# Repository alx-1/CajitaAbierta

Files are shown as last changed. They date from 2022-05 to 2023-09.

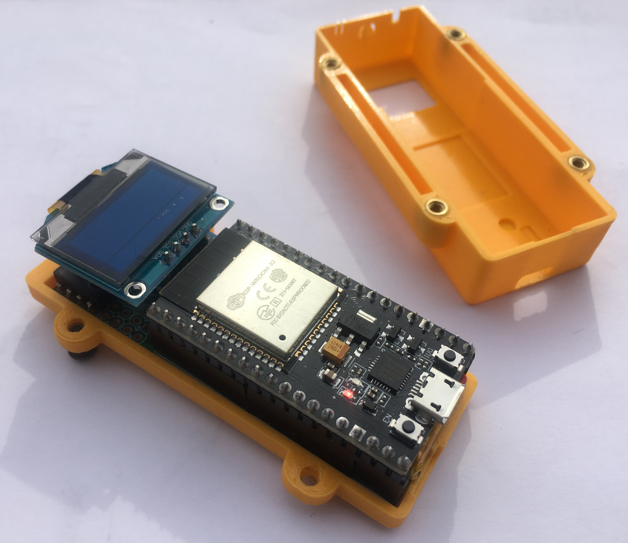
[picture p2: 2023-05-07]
media/images/cajita_abierta_01.JPG

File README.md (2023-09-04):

# CajitaAbierta

The repo for the firmware is now at : https://gitlab.com/darknessdesigner/cajitaabierta

Start with the howtos : https://github.com/alx-1/CajitaAbierta/wiki

Breakout wireless sensor circuit + software for the nodemcu ESP32S board.

Can send sensor data to :

touchOSCBridge

chataigne

hydra over node

and the TDLF module : https://github.com/alx-1/technologies-de-la-fete

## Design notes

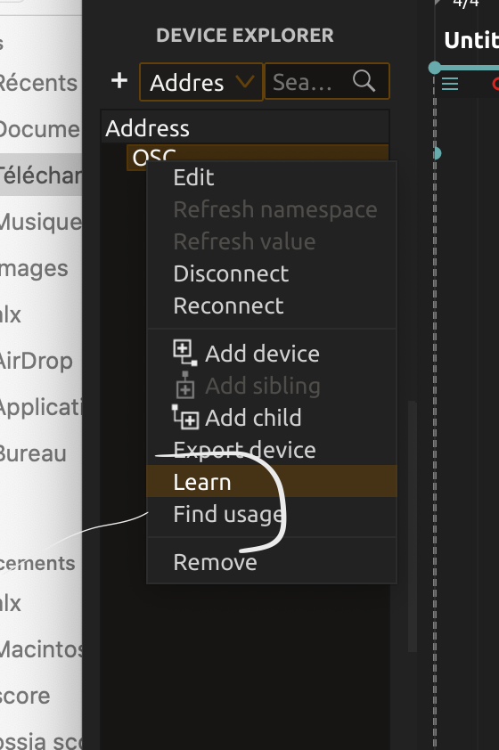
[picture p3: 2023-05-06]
media/images/ossia_osc_learn.png

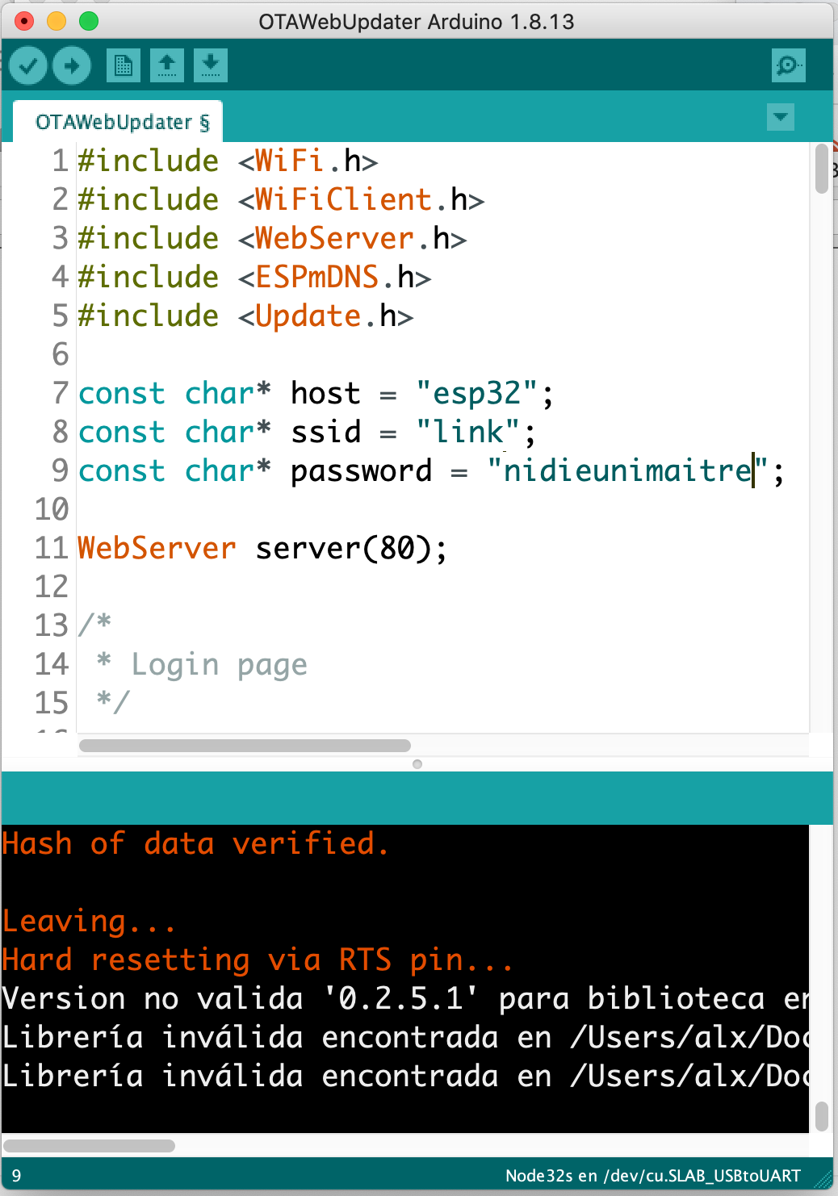
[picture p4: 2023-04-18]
media/images/OTAWebUpdater_change_credentials.png

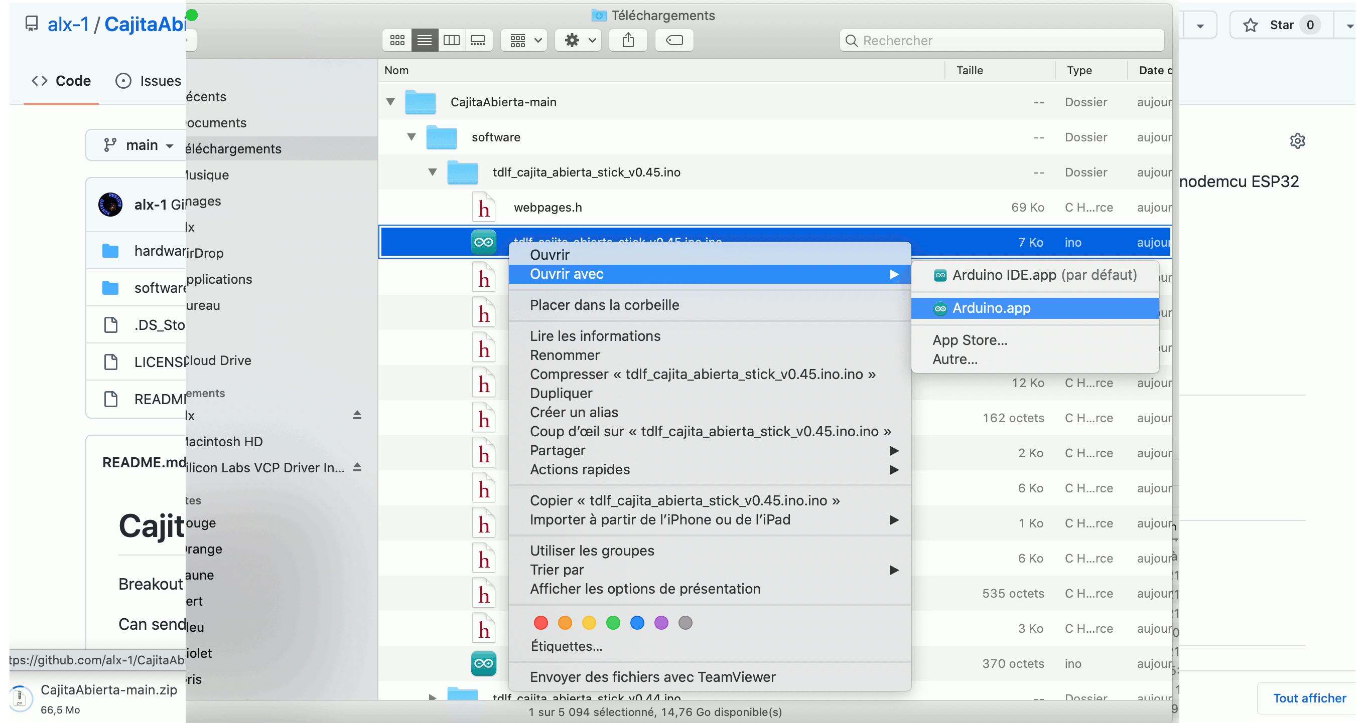
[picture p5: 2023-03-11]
media/CajitaAbierta_github_descargar.gif

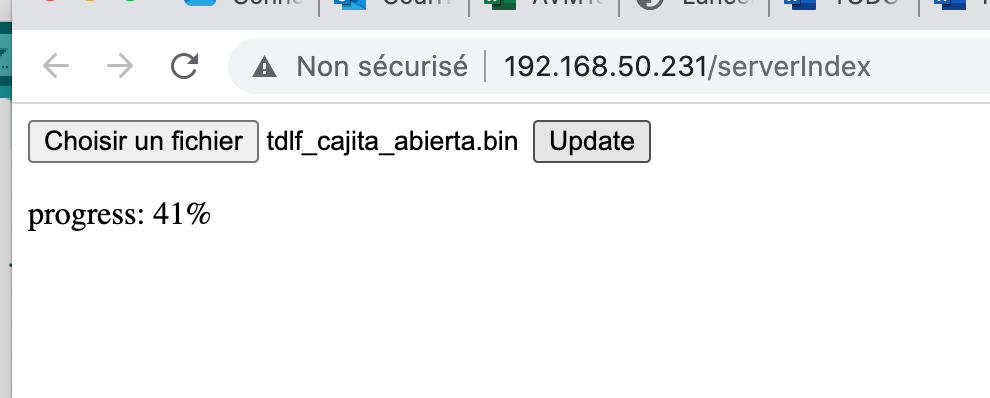
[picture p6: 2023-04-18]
media/images/web_updating.png

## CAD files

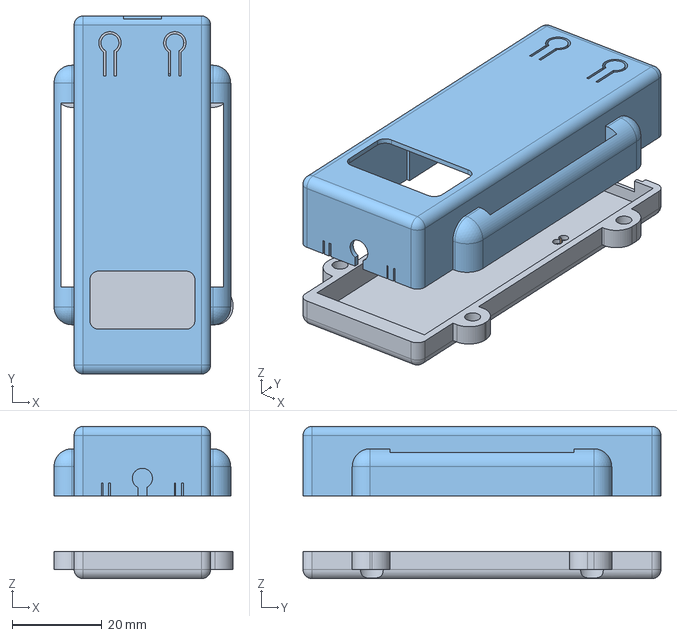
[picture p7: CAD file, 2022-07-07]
hardware/CajitaAbierta_stick v8.step
40.0 x 80.0 x 34.0 mm

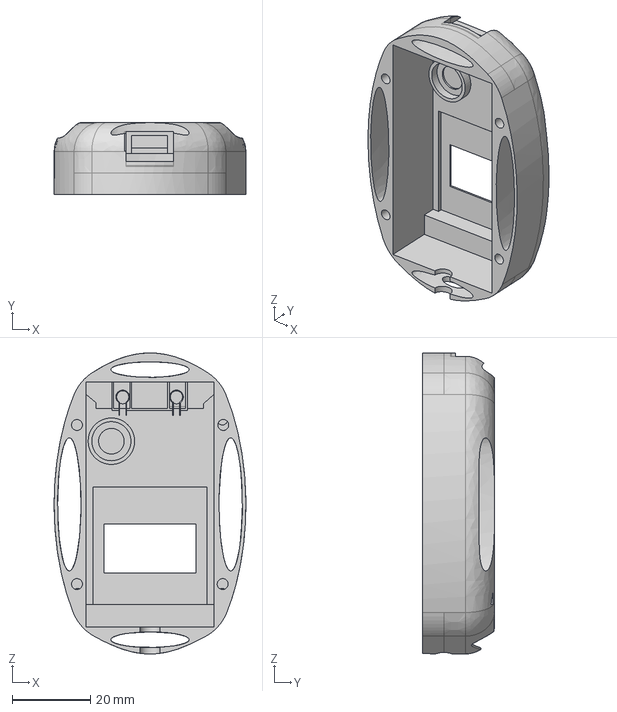
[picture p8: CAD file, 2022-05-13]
hardware/Cajita_abierta_top.step
49.0 x 18.5 x 76.9 mm

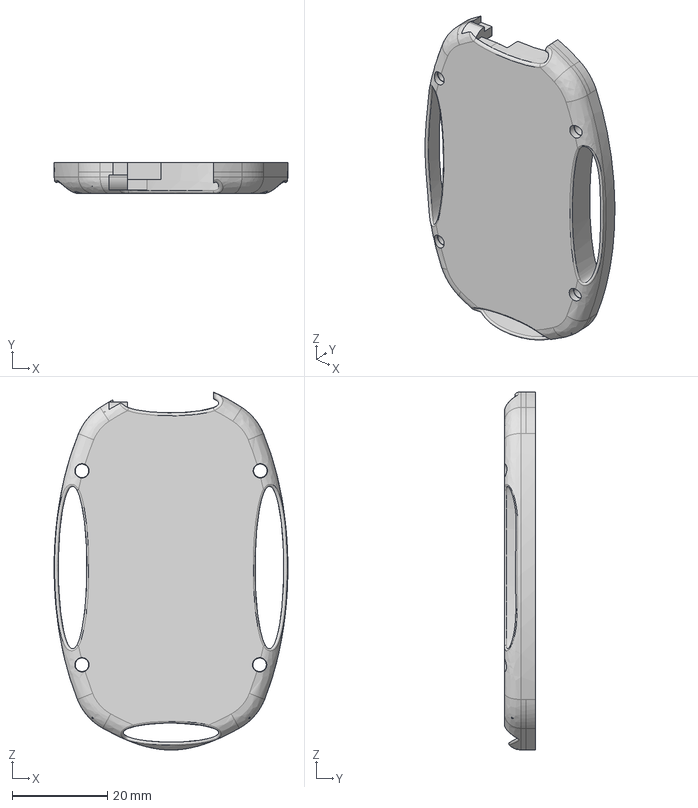
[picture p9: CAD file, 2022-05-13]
hardware/Cajita_abierta_bas.step
49.0 x 6.50 x 75.0 mm

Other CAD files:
hardware/Cajita_abierta_bas.dwg
hardware/Cajita_abierta_top.dwg

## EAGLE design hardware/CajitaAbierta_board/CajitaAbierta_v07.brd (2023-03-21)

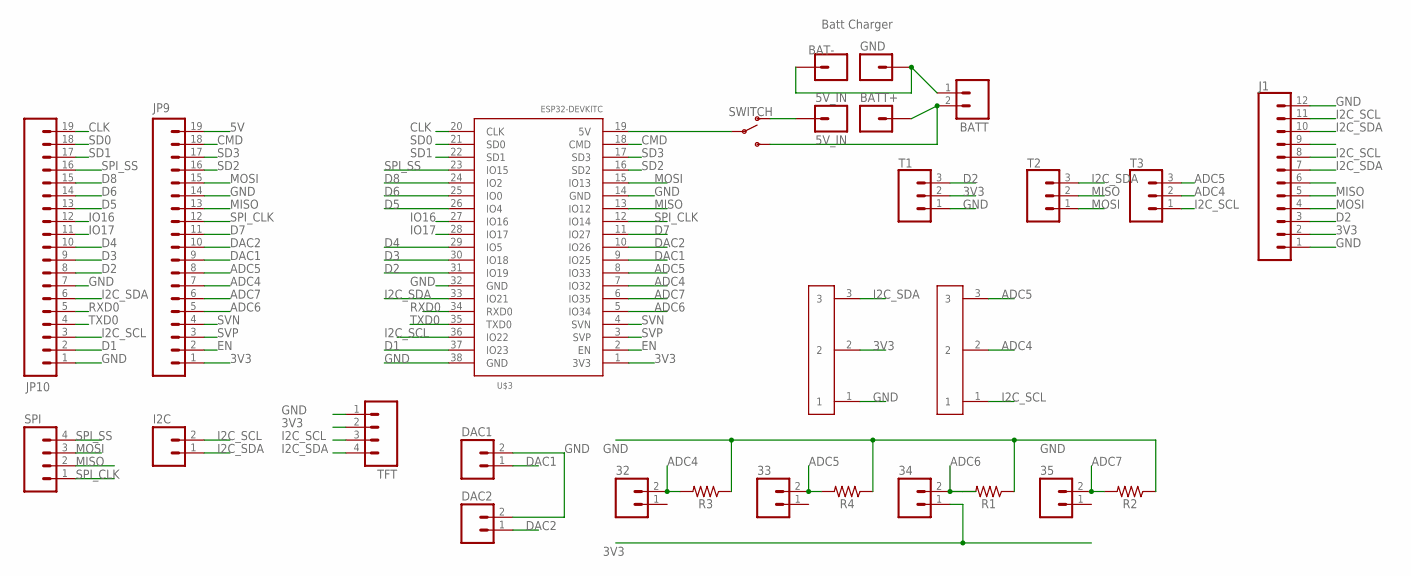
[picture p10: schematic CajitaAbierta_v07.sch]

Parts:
5V_IN: 5V_IN; 1X01
32, 33, 34, 35: M02PTH; 1X02
BAT-: M01PTH; 1X01
BATT: M02LOCK_LONGPADS; 1X02_LOCK_LONGPADS
BATT+: M01PTH; 1X01
DAC1, DAC2: M02PTH; 1X02
GND: Batt Charger; 1X01
I2C: M02PTH; 1X02
J1: CONN_12NO_SILK; 1X12_NO_SILK
JP9, JP10: M191X19; 1X19
R1, R2, R3, R4: 1206
SPI: M04PTH; 1X04
SWITCH: SWITCH-SPDT-SMD-RIGHT-ANGLE; SWITCH_SPST_SMD_A
T1, T2, T3: CONN_03SCREW-NS; SCREWTERMINAL-3.5MM-3-NS
TFT: M04PTH; 1X04
U$3: ESP32DEVKITC; ESP32-DEVKITC
U$4, U$5: SCREW_TERMINAL_3_POS_5MM

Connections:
3V3: 34.1, J1.2, JP9.1, T1.2, TFT.2, U$3.1 (3V3), U$4.2
5V: JP9.19, SWITCH.2, U$3.19 (5V)
5V_IN: 5V_IN.1, SWITCH.1 (O)
ADC4: 32.2, JP9.7, R3.2, T3.2, U$3.7 (IO32), U$5.2
ADC5: 33.2, JP9.8, R4.2, T3.3, U$3.8 (IO33), U$5.3
ADC6: 34.2, JP9.5, R1.2, U$3.5 (IO34)
ADC7: 35.2, JP9.6, R2.2, U$3.6 (IO35)
BATT+: BATT.2, BATT+.1, SWITCH.3 (S)
CLK: JP10.19, U$3.20 (CLK)
CMD: JP9.18, U$3.18 (CMD)
D1: JP10.2, U$3.37 (IO23)
D2: J1.3, JP10.8, T1.3, U$3.31 (IO19)
D3: JP10.9, U$3.30 (IO18)
D4: JP10.10, U$3.29 (IO5)
D5: JP10.13, U$3.26 (IO4)
D6: JP10.14, U$3.25 (IO0)
D7: JP9.11, U$3.11 (IO27)
D8: JP10.15, U$3.24 (IO2)
DAC1: DAC1.1, JP9.9, U$3.9 (IO25)
DAC2: DAC2.1, JP9.10, U$3.10 (IO26)
EN: JP9.2, U$3.2 (EN)
GND: BAT-.1, BATT.1, DAC1.2, DAC2.2, GND.1, J1.1, J1.12, JP9.14, JP10.1, JP10.7, R1.1, R2.1, R3.1, R4.1, T1.1, TFT.1, U$3.14 (GND), U$3.32 (GND), U$3.38 (GND), U$4.1
I2C_SCL: I2C.2, J1.8, J1.11, JP10.3, T3.1, TFT.3, U$3.36 (IO22), U$5.1
I2C_SDA: I2C.1, J1.7, J1.10, JP10.6, T2.3, TFT.4, U$3.33 (IO21), U$4.3
IO16: JP10.12, U$3.27 (IO16)
IO17: JP10.11, U$3.28 (IO17)
MISO: J1.5, JP9.13, SPI.2, T2.2, U$3.13 (IO12)
MOSI: J1.4, JP9.15, SPI.3, T2.1, U$3.15 (IO13)
RXD0: JP10.5, U$3.34 (RXD0)
SD0: JP10.18, U$3.21 (SD0)
SD1: JP10.17, U$3.22 (SD1)
SD2: JP9.16, U$3.16 (SD2)
SD3: JP9.17, U$3.17 (SD3)
SPI_CLK: JP9.12, SPI.1, U$3.12 (IO14)
SPI_SS: JP10.16, SPI.4, U$3.23 (IO15)
SVN: JP9.4, U$3.4 (SVN)
SVP: JP9.3, U$3.3 (SVP)
TXD0: JP10.4, U$3.35 (TXD0)

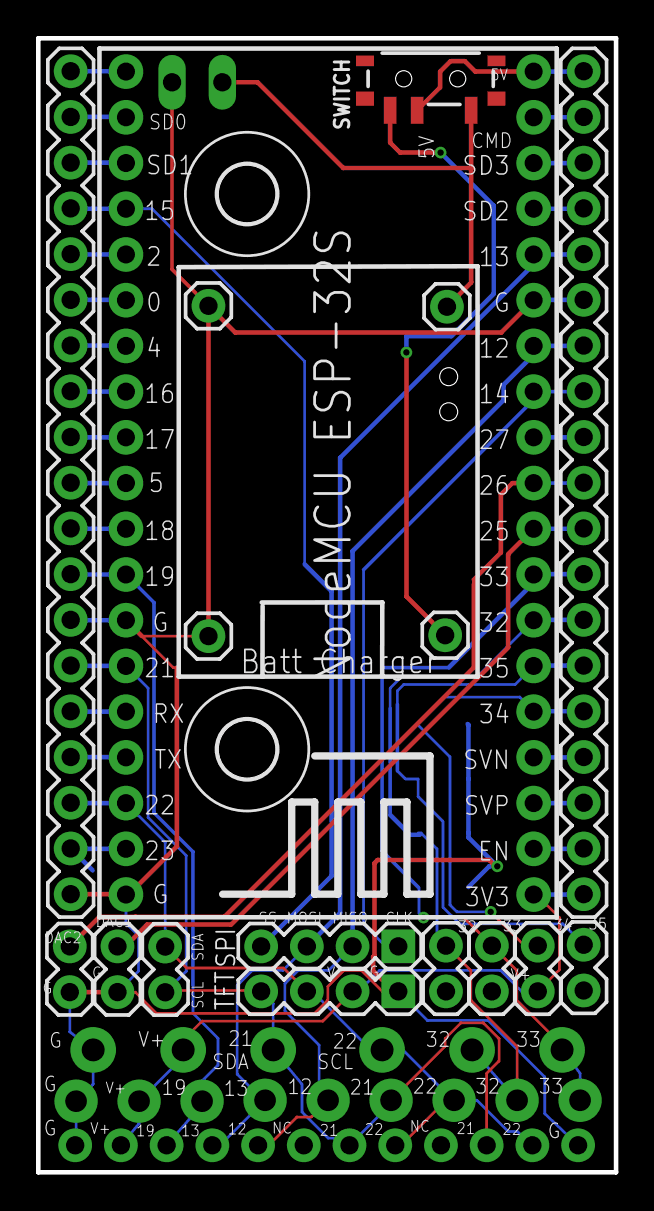
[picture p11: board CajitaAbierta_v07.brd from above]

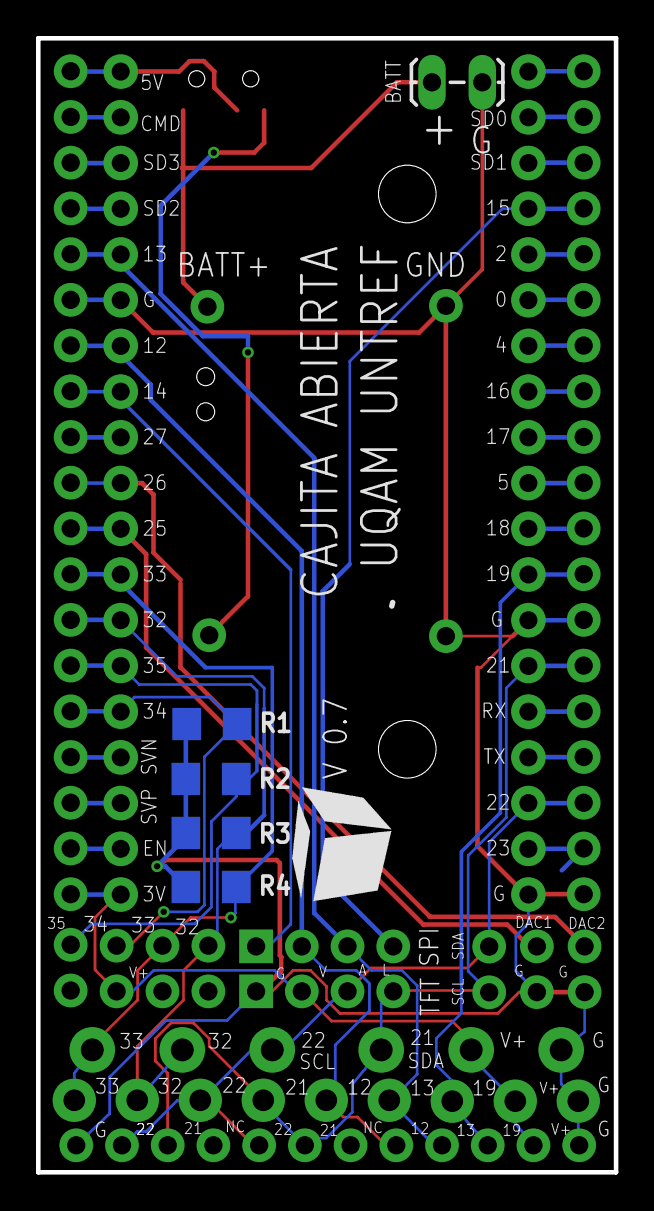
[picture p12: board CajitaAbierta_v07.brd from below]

Board: 2 copper layers, 32.1 x 63.0 mm, 30 parts (5 on the bottom side), 38 nets.

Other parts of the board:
U$1, U$2: 3,2

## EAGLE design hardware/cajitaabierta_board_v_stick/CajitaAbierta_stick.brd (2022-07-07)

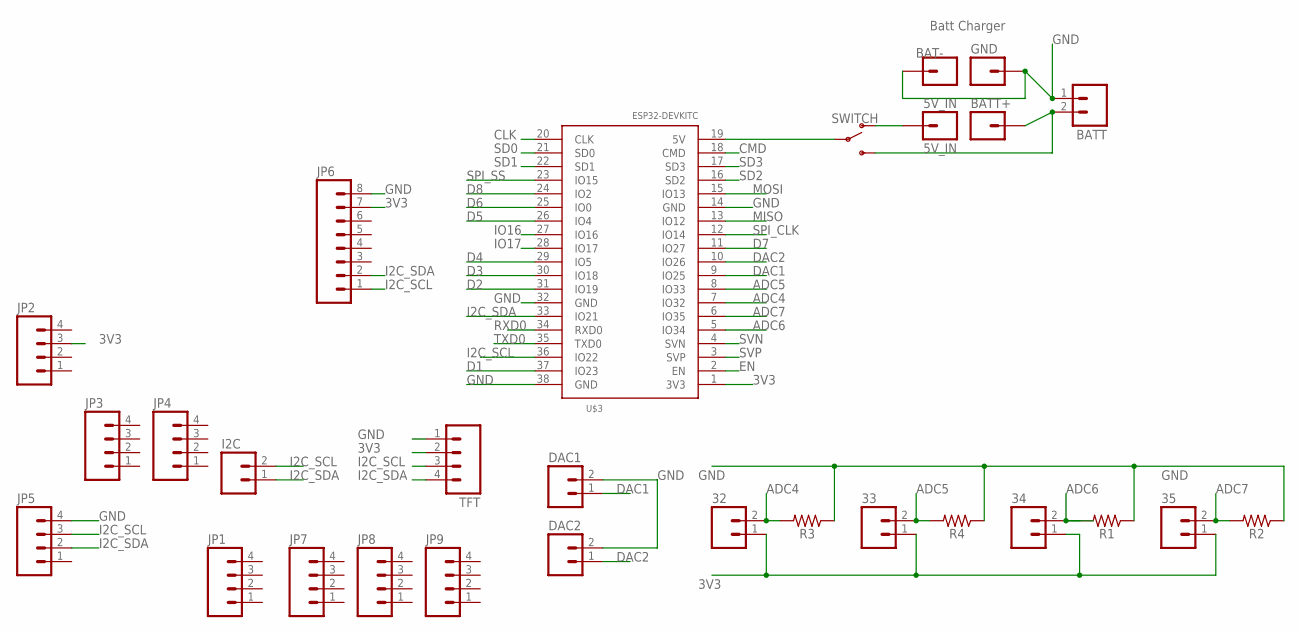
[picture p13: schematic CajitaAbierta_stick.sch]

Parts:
5V_IN: 5V_IN; 1X01
32, 33, 34, 35: M02PTH; 1X02
BAT-: M01PTH; 1X01
BATT: M02LOCK_LONGPADS; 1X02_LOCK_LONGPADS
BATT+: M01PTH; 1X01
DAC1, DAC2: M02PTH; 1X02
GND: Batt Charger; 1X01
I2C: M02PTH; 1X02
JP1, JP2, JP3, JP4, JP5, JP7, JP8, JP9: M04NO_SILK_ALL_ROUND; 1X04_NO_SILK_ALL_ROUND
JP6: M08; 1X08_ROUND
R1, R2, R3, R4: 1206
SWITCH: SWITCH-SPDT-SMD-RIGHT-ANGLE; SWITCH_SPST_SMD_A
TFT: M04PTH; 1X04
U$3: ESP32DEVKITC; ESP32-DEVKITC

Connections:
3V3: 32.1, 33.1, 34.1, 35.1, JP2.3, JP6.7, TFT.2, U$3.1 (3V3)
5V: SWITCH.2, U$3.19 (5V)
5V_IN: 5V_IN.1, SWITCH.1 (O)
ADC4: 32.2, R3.2, U$3.7 (IO32)
ADC5: 33.2, R4.2, U$3.8 (IO33)
ADC6: 34.2, R1.2, U$3.5 (IO34)
ADC7: 35.2, R2.2, U$3.6 (IO35)
BATT+: BATT.2, BATT+.1, SWITCH.3 (S)
CLK: U$3.20 (CLK)
CMD: U$3.18 (CMD)
D1: U$3.37 (IO23)
D2: U$3.31 (IO19)
D3: U$3.30 (IO18)
D4: U$3.29 (IO5)
D5: U$3.26 (IO4)
D6: U$3.25 (IO0)
D7: U$3.11 (IO27)
D8: U$3.24 (IO2)
DAC1: DAC1.1, U$3.9 (IO25)
DAC2: DAC2.1, U$3.10 (IO26)
EN: U$3.2 (EN)
GND: BAT-.1, BATT.1, DAC1.2, DAC2.2, GND.1, JP5.4, JP6.8, R1.1, R2.1, R3.1, R4.1, TFT.1, U$3.14 (GND), U$3.32 (GND), U$3.38 (GND)
I2C_SCL: I2C.2, JP5.3, JP6.1, TFT.3, U$3.36 (IO22)
I2C_SDA: I2C.1, JP5.2, JP6.2, TFT.4, U$3.33 (IO21)
IO16: U$3.27 (IO16)
IO17: U$3.28 (IO17)
MISO: U$3.13 (IO12)
MOSI: U$3.15 (IO13)
RXD0: U$3.34 (RXD0)
SD0: U$3.21 (SD0)
SD1: U$3.22 (SD1)
SD2: U$3.16 (SD2)
SD3: U$3.17 (SD3)
SPI_CLK: U$3.12 (IO14)
SPI_SS: U$3.23 (IO15)
SVN: U$3.4 (SVN)
SVP: U$3.3 (SVP)
TXD0: U$3.35 (TXD0)

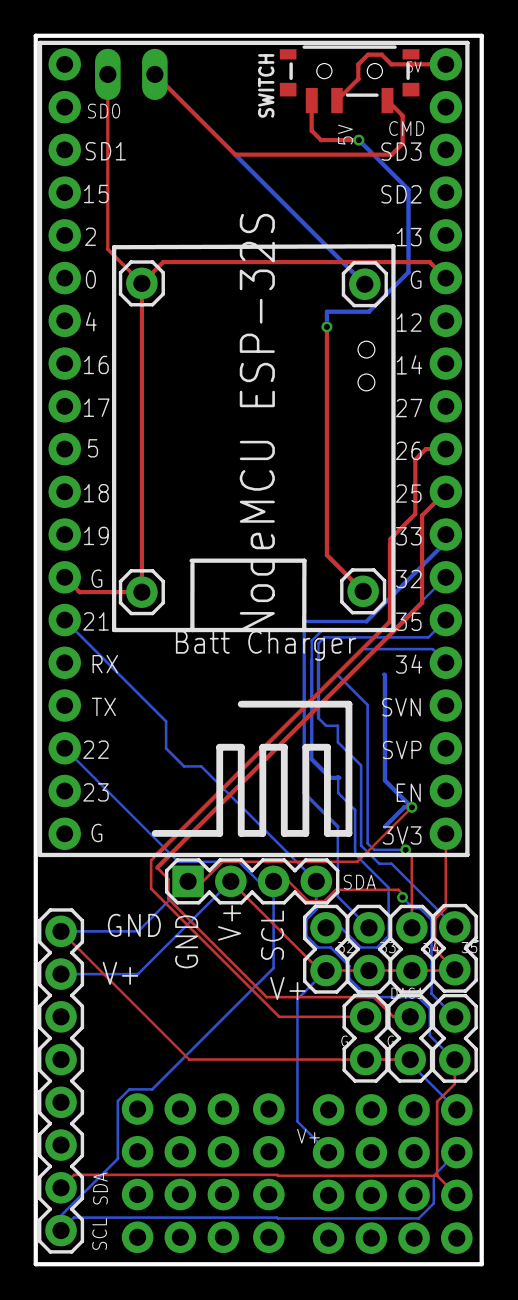
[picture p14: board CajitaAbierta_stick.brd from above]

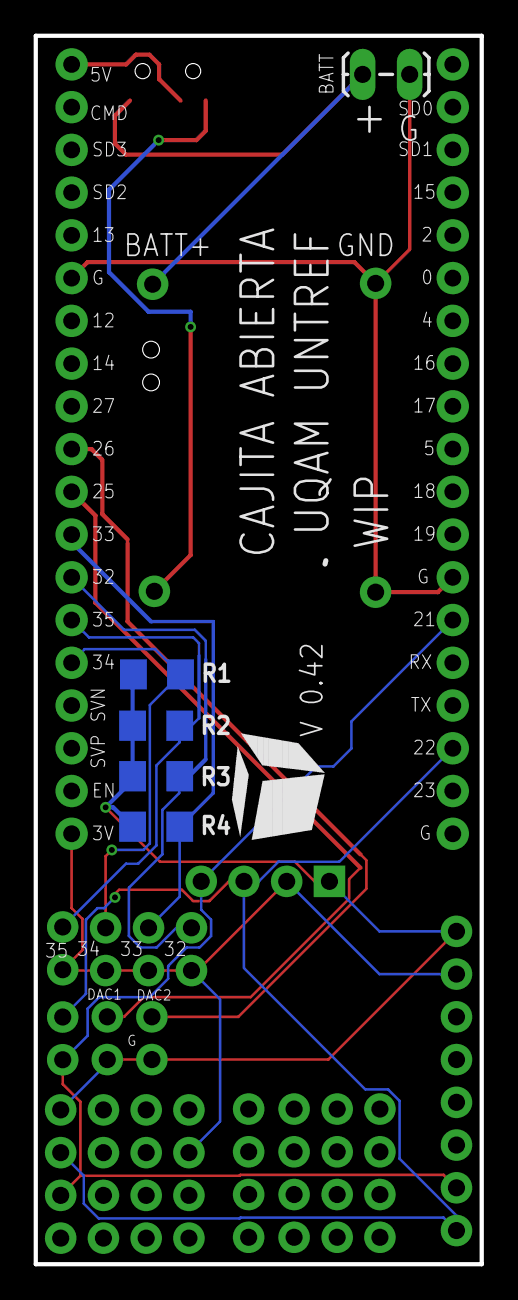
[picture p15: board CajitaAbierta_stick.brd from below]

Board: 2 copper layers, 26.5 x 73.0 mm, 28 parts (5 on the bottom side), 13 nets.

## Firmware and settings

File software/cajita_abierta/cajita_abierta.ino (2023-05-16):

#include "config.h"

//// Sensors ////
const long period = 2; //time between samples in milliseconds // change from '10' to '5' when not printing to serial
long startMillis = 0;
unsigned long lastTime = 0;
bool portalStart = false;

#include <microsmooth.h>
uint16_t *history1 = ms_init(EMA); // microsmooth init
uint16_t *history2 = ms_init(EMA); // microsmooth init

#include "blowsuck.h"
#include "params.h"
#include "analogSensors.h"
#include "accelerometer.h"
#include "button.h"
#include "display.h"
#include "WiFI_.h"
#include "portal.h"
#include "record_play.h"
#include <analogWrite.h> // From the polyfill analogWrite library for ESP32 //
#include "UDP_OSC_Midi.h"


void setup() {
    //WiFi.mode(WIFI_STA); // explicitly set mode, esp defaults to STA+AP    
    Serial.begin(115200);
    #if defined Display
    displaySetup();
    #endif
    #if defined Accelerometer
    accelerometerSetup();
    #endif
    #if defined PressureSensor
    pressureSensorSetup();
    #endif
    #if defined useButton
    buttonSetup();
    #endif
    preferencesSetup();
    preferencesGet();
    if(myMode == "live"){
      displayMessage(9,0);
      } else if (myMode == "playback"){
      displayMessage(10,0);
      littleFSSetup();
      readArrayFromFile(); 
      } else if (myMode == "record"){
      displayMessage(11,0);
      } else if (myMode == "formatFS"){
      displayMessage(12,0);
      }
    
    if(myMode == "live" || myMode == "playback" || myMode ==""){  // myMode = live, playback, record
      //    live : start wifi, start osc, check sensors, send according to the bpm  
      //    playback : start wifi, populate array from file, start osc, send according to the bpm 
      Serial.println(ssid.c_str());
      Serial.println(password.c_str());
      WiFi.begin(ssid.c_str(),password.c_str());
    
      if(testWifi()==false){
        startPortal();  
        }

      if (!MDNS.begin("CajitaAbierta")) {
        Serial.println("Error setting up MDNS responder!");
        while(1){
          delay(1000);
        }
      }

      if(checkedTOSCB == "checked"){
        browseService("touchoscbridge", "udp");  
      } else if(checkedTDLF == "checked"){ 
        browseService("tdlf", "udp");   
      } else if(checkedOSC == "checked"){ 
        browseService("osc", "udp"); // _osc._udp // like chataigne
      }
      
      } else if (myMode == "formatFS"){
        // formatFS : don't start wifi, just reformat the File System and reboot in live mode
        Serial.println("Format File System");
        littleFSSetup();
        littleFSFormat();
      } else if (myMode == "record"){
        //    record : don't start wifi, check sensors, save to array , then save to file, then reboot into play mode
        littleFSSetup();
        Serial.println("We're recording");
    }
    getMacAddress();
      
}

void loop() {

    // myMode = live, playback, record
    
    if(myMode == "live" || myMode ==""){  
      // Serial.println("myMode: Live"); // Enabling this slows down the server
      if((WiFi.status() == WL_CONNECTED)) {
        if (portalStart){
          Serial.println("Starting portal");
          startPortal();
        }

      #if defined Accelerometer
      checkAccelerometer();
      #endif
      #if defined PressureSensor
      readCFSensor(0x6D);   //start conversion and read on pressure sensor at 0x6D address
      #endif
      #if defined useButton
      getButtonState();
      #endif
      #if defined useAnalogSensors
      //Serial.println("reading them analog sensors");
      readSensors(); 
      #endif
      sendOSCMidi();
      #if defined Display
      // Serial.print("buttonCounter : ");Serial.println(buttonCounter); 
      if(buttonCounter == 0){
        displayMessage(2,0); // Overall sensors 
        }else{
        displayMessage(3,0); // Single sensor display 
        }
      #endif
       while ((millis() - startMillis) < period);      //waits until period done
       } else {
        serverListen();
        }
  
    } else if (myMode == "playback"){

      if((WiFi.status() == WL_CONNECTED)) {
        monIP = WiFi.localIP();
        if (portalStart){
          Serial.println("Starting portal");
          startPortal();
        }
      //readArrayFromFileToFile();

      
      #if defined Accelerometer
      playbackAccelerometer();
      #endif
      #if defined PressureSensor
      playbackCFSensor(0x6D);   //start conversion and read on pressure sensor at 0x6D address
      #endif
      #if defined useButton
      getButtonState();
      #endif
      #if defined useAnalogSensors
      playbackReadSensors();
      #endif
      sendOSCMidi();
      #if defined Display
      // Serial.print("buttonCounter : ");Serial.println(buttonCounter); 
      if(buttonCounter == 0){
        displayMessage(2,0); // Overall sensors 
        }else{
        displayMessage(3,0); // Single sensor
        }
       #endif
       sensorIndex = sensorIndex+12;
       // Serial.print("sensorIndex : ");Serial.println(sensorIndex);
       if(sensorIndex > monArrayLength.toInt()){
        sensorIndex = 0; // reset
       }
      } else {
        serverListen();
        }
    } else if (myMode == "record"){

      sensorIndex = 0;

      // Countdown !! // 
      Serial.print("monDelai : ");Serial.println(monDelai);
      countDownFrom = int(monDelai.toInt()); // c_str())).toInt()
      Serial.print("countDownFrom : ");Serial.println(countDownFrom);
      
      for(countDownFrom;countDownFrom>=0;countDownFrom--){
        Serial.print("countDownFrom : ");Serial.println(countDownFrom);
        displayMessage(15,countDownFrom); // 
        delay(1000);  
      }

      Serial.print("monArrayLength : ");Serial.println(monArrayLength);
      
      while(sensorIndex < monArrayLength.toInt()){
        //  record : don't start wifi, check sensors, populate array , then save to file, then reboot into play mode
        Serial.print("Recording, ");Serial.print("sensorIndex : ");Serial.println(sensorIndex);
        #if defined Accelerometer
        checkAccelerometer();
        #endif
        #if defined PressureSensor
        checkCFSensor(0x6D);   //start conversion and read on pressure sensor at 0x6D address
        #endif
        #if defined useButton
        //getButtonState();
        #endif
        #if defined useAnalogSensors
        readSensors();
        #endif
        #if defined Display
        // Serial.print("buttonCounter : ");Serial.println(buttonCounter); 
        if (sensorIndex % 144){
        if(buttonCounter == 0){
          displayMessage(2,1); // Overall sensors 
          }else{
          displayMessage(3,1); // Single sensor
          }
        }
       #endif
       while ((millis() - startMillis) < period);      //waits until period done
       
       // Recording /// Get the values in an array !  Get ax, ay, az, x, y, z, blow, suck, s1, s2, s3, s4 into that thing
       
       for ( int i = 0; i <12; i++ ) { 
        switch(i){
        #if defined Accelerometer
        case 0: sensorData[i+sensorIndex] = aIntX; break; 
        case 1: sensorData[i+sensorIndex] = aIntY; break;
        case 2: sensorData[i+sensorIndex] = aIntZ; break;
        case 3: sensorData[i+sensorIndex] = x; break;
        case 4: sensorData[i+sensorIndex] = y; break;
        case 5: sensorData[i+sensorIndex] = z; break;
        #endif
        #if  defined PressureSensor
        case 6: sensorData[i+sensorIndex] = blowValue; break;
        case 7: sensorData[i+sensorIndex] = suckValue; break;
        #endif
        case 8: sensorData[i+sensorIndex] = sensor1Value; break;
        case 9: sensorData[i+sensorIndex] = sensor2Value; break;
        case 10: sensorData[i+sensorIndex] = sensor3Value; break;
        case 11: sensorData[i+sensorIndex] = sensor4Value; break;
        default: break;
      } 
    }
    sensorIndex = sensorIndex+12;   
    } // end of while
     writeToFile(); // at the end of which restart in playback mode
     preferences.putString("myMode","playback");
     preferences.putString("checkedLive","unchecked");
     preferences.putString("checkedPlay","checked");
     preferences.putString("checkedRecord","unchecked");
     preferences.putString("checkedFormatFS","unchecked");
     ESP.restart();
     } else if (myMode=="calibrating"){
      // Serial.println("myMode : calibrating");
      #if defined Accelerometer
      checkAccelerometer();
      #endif
      #if defined PressureSensor
      readCFSensor(0x6D);   //start conversion and read on pressure sensor at 0x6D address
      #endif
      #if defined useButton
      getButtonState();
      #endif
      #if defined useAnalogSensors
      readSensors(); 
      #endif
     
     }else {
      serverListen();
      }
 
}

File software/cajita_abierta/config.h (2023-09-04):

 #define Accelerometer true
// #define PressureSensor true
#define Display true
#define displayRotate true // Enable for the accelerometer version of the cajita
#define useButton true
#define useAnalogSensors true
#ifndef LED_BUILTIN
#define LED_BUILTIN 2 // For the boards that do not have a LED_BUILTIN
#endif

void sendSensorsData(String someValue);

void listFile(String someOtherValue);
void writeFile(String myFile, String myMessage);

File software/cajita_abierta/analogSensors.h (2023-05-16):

#if defined useAnalogSensors

int sensor1Value = 0; 
int sensor2Value = 0; 
int sensor3Value = 0; 
int sensor4Value = 0; 

void readSensors(){  // check the sensors here
    // Serial.println("reading sensors");
 
    if ( sensor1 == "checked" ){
      sensor1Value = analogRead(32); // R3 // 32
      Serial.print("sensor1Value : ");Serial.println(sensor1Value);
      if(s1EMAFilter == "checked"){
        sensor1Value = ema_filter(sensor1Value, history1);
        //Serial.print("sensor1Value After EMA filtering : ");Serial.println(sensor1Value);
        }
      // Serial.print("sensor1Min test: ");Serial.println(sensor1Min);
     /* if(sensor1Min.toInt() > sensor1Value){
        sensor1Min = sensor1Value;
        Serial.print("sensor1Min: ");Serial.println(sensor1Min);
        }
      if(sensor1Max.toInt() < sensor1Value){
        sensor1Max = sensor1Value;
        Serial.print("sensor1Max: ");Serial.println(sensor1Max);
        }
      */
      if (sensor1Midi == "checked"){
        //sensor1Value = map(sensor1Value,sensor1Min.toInt(),sensor1Max.toInt(),0,127);
        sensor1Value = map(sensor1Value,0,4095,0,127);
        }
      
      } else { sensor2Value = -42; }
      
    if (sensor2 == "checked"){
      sensor2Value = analogRead(33);  // R4
      //Serial.print("sensor2Value : ");Serial.println(sensor2Value);
      if(s2EMAFilter == "checked"){
        sensor2Value = ema_filter(sensor2Value, history2);
        //Serial.print("sensor2Value After EMA filtering : ");Serial.println(sensor2Value);
      }
      /*
      if(sensor2Min.toInt() > sensor2Value){
        sensor2Min = sensor2Value;
        }
      if(sensor2Max.toInt() < sensor2Value){
        sensor2Max = sensor2Value;
        }
      */
      if (sensor2Midi == "checked"){
        // sensor2Value = map(sensor2Value,sensor2Min.toInt(),sensor2Max.toInt(),0,127);
        sensor2Value = map(sensor2Value,0,4095,0,127);
        }  
      } else { sensor2Value = -42; }
    /*if ( sensor3 == "checked"){
      sensor3Value = analogRead(34);  // R1
      Serial.print("sensor3Value : ");Serial.println(sensor3Value);
      }
    if ( sensor4 == "checked"){
      sensor4Value = analogRead(35);  // R2
      Serial.print("sensor4Value : ");Serial.println(sensor4Value);
      }*/
//    
      if ( calibratingSensors == "analogSensors" ){
        sendSensorsData("analogSensors");   
      }
}

void playbackReadSensors(){
    //Serial.print("sensor1: ");Serial.println(sensor1);
    if ( sensor1 == "checked"){
      sensor1Value = sensorData[sensorIndex+8]; // Read the values from the array
      //Serial.print("sensor1Value at : ");
      //Serial.print(sensorIndex+8);
      //Serial.print(" : ");
      //Serial.println(sensor1Value);
      }
    if ( sensor2 == "checked"){
      sensor2Value = sensorData[sensorIndex+9];
      // Serial.print("sensor2Value : ");
      // Serial.print(sensorIndex+9);
      // Serial.println(sensor2Value);
      }
    if ( sensor3 == "checked"){
      sensor3Value = sensorData[sensorIndex+10];
      }
    if ( sensor4 == "checked"){
      sensor4Value = sensorData[sensorIndex+11];
    }
 
}

void initSensorsCfg(){ // This is needed because radio buttons do not return values if unchecked
  sensor1 = "unchecked";
  s1EMAFilter = "unchecked";
  sensor1Midi = "unchecked";
  sensor2 = "unchecked";
  s2EMAFilter = "unchecked";
  sensor2Midi = "unchecked";
}

#endif

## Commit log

2021-10-01 Initial commit
    Cajita Abierta para enseñar. 'Breakout' board para el Nodemcu ESP32-S. Con 8 salidas/entradas io (servos, luces), 4 analog in para sensores, 2 DACs, SPI, I2C, mini pantallas.
    [CajitaAbierta.brd, CajitaAbierta.sch]
2021-10-01 imagen de la plaqueta
2021-10-01 Last minute changes to version 0.3
    [CajitaAbierta.brd]
2021-10-07 Voltage divider uses V+ as variable resistance
    For Yesi :)
    [CajitaAbierta.brd, CajitaAbierta.sch]
2021-10-16 Arduino Websocket connection to a server
2021-11-07 Updates for ESP32
    Adapted the previous example to work with an ESP32. Udp.write becomes Udp.print and a delay(50) was added to try to get the terminal window to print messages correctly. Unsure why it doesn't work.
2021-11-08 v04 - changes to the TFT connections
    nouvelles étiquettes (labels)
    cambié sdl and sda
    switch on the other side
    [CajitaAbierta.brd, CajitaAbierta.sch]
2021-12-05 V0.4
    Works with tdlf -> UDP send of sensor data.
2022-05-13 added the reception of a message from the server to the client
    A condition and ESP.restart()
    [Cajita_abierta_bas.dwg, Cajita_abierta_bas.step, Cajita_abierta_top.dwg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]
2022-06-09 Now with screw terminals
    More code examples
    [CajitaAbierta.brd, CajitaAbierta.sch]
2022-07-07 Dos nuevas versiones!
    v0.5 : Avec borniers pour les cours de robotique
    v0.42 : 'Sitck' pour interfacer avec des capteurs : Accéléromètre, Pression et autres senseurs analogiques.
    [CajitaAbierta_stick.brd, CajitaAbierta_stick.sch, CajitaAbierta_v05_robotique.brd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]
2022-07-07 Create CajitaAbierta_stick v8.step
    3D case for the stick sensor
    [CajitaAbierta_stick v8.step]
2022-07-07 Create tdlf_cajita_abierta_stick_v0.42.ino
    Code for the 'stick' version of the Cajita Abierta. Features :
    MDNS discovery
    Web configuration
    Interface with Accelerometer, Pressure sensors as well as 4 analogical sensors inputs.
    OSC midi support.
2022-07-09 Update tdlf_cajita_abierta_stick_v0.42.ino
    Switched to LITTLEFS
    Improvements on modes and usability
2022-11-27 Moving to a single board with
    5mm screw terminals for heavier motor controls
    3.5mm screw terminals for lighter wear
    Accelerometer pinout, breath sensor pinout
    [CajitaAbierta_v06_robotique.brd, CajitaAbierta_v06_robotique.sch, CajitaAbierta_v07.brd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]
2023-02-23 Refactoring the code
    Splitting of the main sensors and functions into separate files
    Captive web portal for the configuration and operation
2023-03-09 Gimnasio de arte
2023-03-21 Cajita Abierta v.0.46
    OTA uploading of .bin file
    [CajitaAbierta.brd, CajitaAbierta.sch, CajitaAbierta_stick.brd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]
2023-03-27 v0.47 getting ready for min max ranging through the web portal
    // (done) * improve .bin upload interface
    // (done) * fix bug Sensor1 preferences saving
    // (done) * actually select udp destination (tdlf, chataigne, touchoscbridge) sending based on the user's choice
    // (done) * switch to asynchronous mode to enable ranging via the captive portal
    [README.ino, analogSensors.h, blowsuck.h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]
2023-03-31 EMA filter implemented
    You need to go to http://192.168.1.1/calibrate to test it out.
2023-04-18 Better sensor config

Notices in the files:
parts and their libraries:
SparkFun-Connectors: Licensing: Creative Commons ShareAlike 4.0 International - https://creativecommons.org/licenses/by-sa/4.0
